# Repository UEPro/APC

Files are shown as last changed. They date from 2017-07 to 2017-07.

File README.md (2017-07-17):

# APC
Atari Punk Console<br />

This PCB was designed for a Workshop in Germany, thus the documentation is in German. Contact me if you need a translation (Contact info in folder "Documentation", file "Anleitung_APC").

<b>AKF-WORKSHOP:</b></n>

Hallo ihr Lieben, ich hoffe ihr hattet alle ein tolles Festival und seid gut Heim gekommen. :)

Vielen Dank, dass ihr beim Workshop mitgemacht habt. Es hat mir riesigen Spaß gemacht, mit euch zu Arbeiten und ich hoffe auch ihr hattet Freude am basteln.

Solltet ihr irgendwelche Fragen oder Probleme haben, schreibt mir einfach über github oder schickt mir eine E-Mail (die Adresse steht in der Anleitung oben im Ordner "Documentation").

Ich werde außerdem eine Facebookseite einrichten, damit ihr mich einfacher kontaktieren könnt. Der Link dazu kommt dann hier her.

Schreibt mir gerne auch für weiteres Feedback und Vorschläge.

Nochmals Danke für die tolle Zeit mit euch und das nette Feedback :) Ich hoffe man sieht sich wieder.

Downloadanleitung:<br />
-Einzelne Datei: Rechtsklick auf die Datei → "Ziel speichern unter" anklicken<br />
-Ganzes Archiv: oben rechts den grünen Knopf "Clone or download" anklicken → "Download as ZIP" anklicken → ZIP Archiv entpacken

This project is based on Forrest Mims' III. "Stepped Tone Generator" as published in his great book series "Engineer's Mini-Notebook".

<br /><span xmlns:dct="http://purl.org/dc/terms/" property="dct:title">Atari Punk Console</span> by <a xmlns:cc="http://creativecommons.org/ns#" href="https://github.com/UEPro/" property="cc:attributionName" rel="cc:attributionURL">Useless Electronics Projects</a> is licensed under a <a rel="license" href="http://creativecommons.org/licenses/by-sa/4.0/">Creative Commons Attribution-ShareAlike 4.0 International License</a>.<br />

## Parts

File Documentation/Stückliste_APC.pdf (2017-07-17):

## AtariPunkConsole – Bill of Materials (github.com/UEPro/APC)

Type | Manufacturer | Model | Specification | Package | Value | N | Part-Nr | Designators
Resistor | Royal Ohm | Metal film resistor | 0,6W; 250V; 50ppm/K | THT-axial | 1 kΩ ±1% | 1 MF006FF1001A50 | | R3
Resistor | Royal Ohm | Metal film resistor | 0,6W; 250V; 50ppm/K | THT-axial | 10 kΩ ±1% | 1 MF006FF1002A50 | | R2
Resistor | Royal Ohm | Metal film resistor | 125mW; 150V= | SMD-0805 | 100 kΩ ±1% | 1 0805S8F1003T5E | | R1
Potentiometer | Alps | R12L | log. stereo | THT-radial | 10 kΩ | 1 RK12L12C0A0G | | VR3
Potentiometer | Generic | | lin. mono | THT-radial | 500 kΩ | 2 | | VR1-2
Capacitor | Kemet | MLCC | 50V; X7R | THT 100mil | 10 nF ±20% | 2 C315C103M5R5TA | | C4, C7
Capacitor | Kemet | MLCC | 50V; X7R | THT 200mil | 100 nF ±10% | 2 C322C104K5R5TA | | C3, C6
Capacitor | Kemet | Polyester Capacitor | 63VAC; 100VDC | THT 200mil | 10 nF ±10% | 1 R82EC2100DQ50K | | C2
Capacitor | Kemet | Polyester Capacitor | 63VAC; 100VDC | THT 200mil | 100 nF ±10% | 1 R82EC3100DQ70K | | C5
Capacitor | Wima | Polyester Capacitor | 63VAC; 100VDC | THT 200mil | 2,2 µF ±10% | 2 | MKS2D042201N00KO 00 | C8-9
Capacitor | Nichicon | Electrolytic Capacitor | 16V; ø6,3mm | THT-radial | 220 µF ±20% | 1 UVZ1C221MED | | C1
Diode | Diotec | ZMM4.7 | Z-Diode; 0,5W | MiniMELF | 4,7 V | 1 ZMM4.7 | | D1
Diode | Optosupply | LED | cyan 3mm | THT-radial | | 1 OSC34L3131A | | D2
Transistor | Fairchild | FDN304 | P-Ch. MOSFET | SOT-23 | | 1 FDN304P | | Q1
IC | TI | NE555 | | DIP-8 | | 2 NE555P | | U1-2
Switch | Generic | | SPDT Slide Switch | THT-radial | | 1 | | S1
Connector | Generic | Pin header | 1x2pin | THT 100mil | | 1 | | J1, J2
Connector | Generic | Pin header connector | 1x2pin | THT 100mil | | 1
Connector | Generic | Crimp Contacts | Female | | | 2
Connector | Lumberg | | Stereo 3,5mm TRS-Jack | THT | | 1 1503 07 | | J3
Connector | Generic | Battery Clip | 9V-Block | | | 1
PCB | | | | | | 1
Case | Gainta | | | | | 1 G1068B
Speaker | NOS | | 8ohm | | | 1
Battery | Duracell | 9V Industrial | 6LR61 | | | 1

NB: These are the parts I have used, mostly because I had them in stock. Other parts with other values/tolerances or from other manufacturers may work just as well or even better.

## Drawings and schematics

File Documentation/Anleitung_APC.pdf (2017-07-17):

# Atari Punk Console

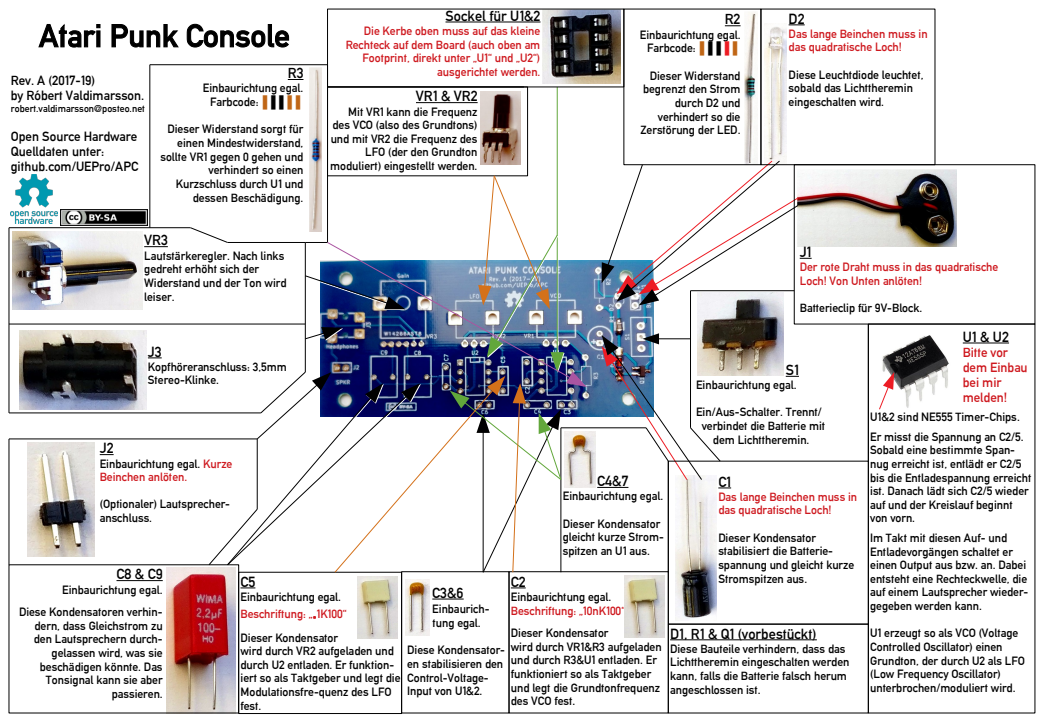
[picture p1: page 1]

Sockel für U1&2 Die Kerbe oben muss auf das kleine Rechteck auf dem Board (auch oben am Footprint, direkt unter „U1“ und „U2“) ausgerichtet werden. | R2 Einbaurichtung egal. Farbcode:▐▐▐▐▐ Dieser Widerstand begrenzt den Strom durch D2 und verhindert so die Zerstörung der LED. | D2 Das lange Beinchen muss in das quadratische Loch! Diese Leuchtdiode leuchtet, sobald das Lichttheremin eingeschalten wird.

Rev. A (2017-19)
by Róbert Valdimarsson.
robert.valdimarsson@posteo.net
Open Source Hardware
Quelldaten unter:
github.com/UEPro/APC

VR1 & VR2 Mit VR1 kann die Frequenz des VCO (also des Grundtons) und mit VR2 die Frequenz des LFO (der den Grundton moduliert) eingestellt werden.

Dieser Widerstand sorgt für
einen Mindestwiderstand,
sollte VR1 gegen 0 gehen und

Lautstärkeregler. Nach links
gedreht erhöht sich der
Widerstand und der Ton wird
leiser.

Der rote Draht muss in das quadratische
Loch! Von Unten anlöten!

Ein/Aus-Schalter. Trennt/
verbindet die Batterie mit
dem Lichttheremin.

U1&2 sind NE555 Timer-Chips.
Er misst die Spannung an C2/5.
Sobald eine bestimmte Span-
nug erreicht ist, entlädt er C2/5
bis die Entladespannung erreicht
ist. Danach lädt sich C2/5 wieder
auf und der Kreislauf beginnt
von vorn.
Im Takt mit diesen Auf- und
Entladevorgängen schaltet er
einen Output aus bzw. an. Dabei
entsteht eine Rechteckwelle, die
auf einem Lautsprecher wieder-
gegeben werden kann.

Das lange Beinchen muss in
das quadratische Loch!

Dieser Kondensator
stabilisiert die Batterie-
spannung und gleicht kurze
Stromspitzen aus.

Einbaurichtung egal.
Beschriftung: „10nK100“
wird durch VR1&R3 aufgeladen
und durch R3&U1 entladen. Er
funktioniert so als Taktgeber
und legt die Grundtonfrequenz
des VCO fest.

Diese Kondensatoren verhin-
dern, dass Gleichstrom zu
den Lautsprechern durch-
gelassen wird, was sie
beschädigen könnte. Das
Tonsignal kann sie aber

D1, R1 & Q1 (vorbestückt)
Diese Bauteile verhindern, dass das
Lichttheremin eingeschalten werden
kann, falls die Batterie falsch herum
angeschlossen ist.

wird durch VR2 aufgeladen und
durch U2 entladen. Er funktion-
iert so als Taktgeber und legt die
Modulationsfre-quenz des LFO
fest.

U1 erzeugt so als VCO (Voltage
Controlled Oscillator) einen
Grundton, der durch U2 als LFO
(Low Frequency Oscillator)
unterbrochen/moduliert wird.

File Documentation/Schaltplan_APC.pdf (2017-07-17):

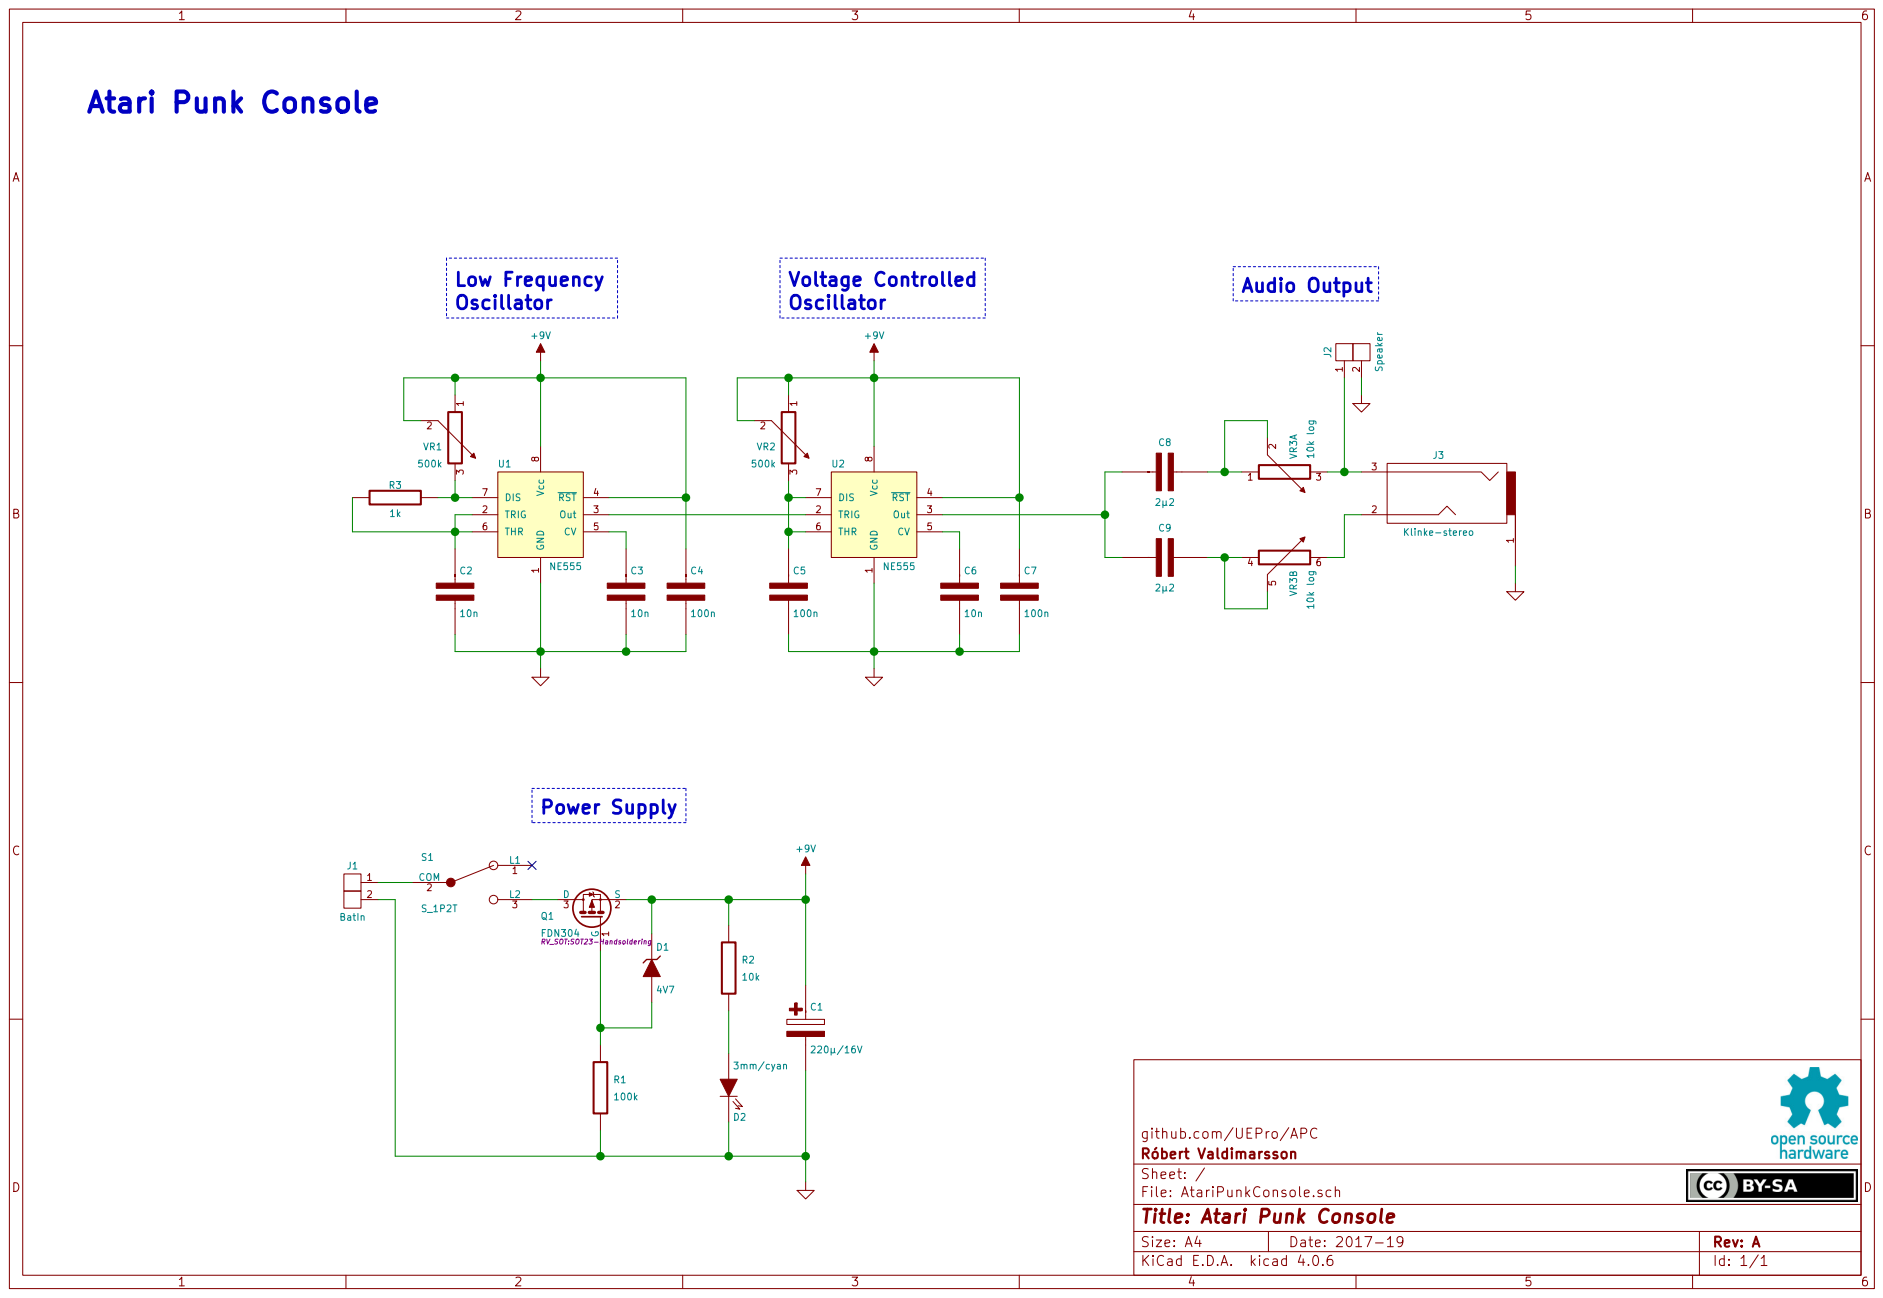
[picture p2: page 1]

1 TRIG 2 Out 3 RST 4 CV 5 THR 6 DIS 7 Vcc 8U1 NE555 GND

1 TRIG 2 Out 3 RST 4 CV 5 THR 6 DIS 7 Vcc 8U2 NE555 C3

github.com/UEPro/APC
File: AtariPunkConsole.sch Sheet: / Róbert Valdimarsson

Id: 1/1 Title: Atari Punk Console

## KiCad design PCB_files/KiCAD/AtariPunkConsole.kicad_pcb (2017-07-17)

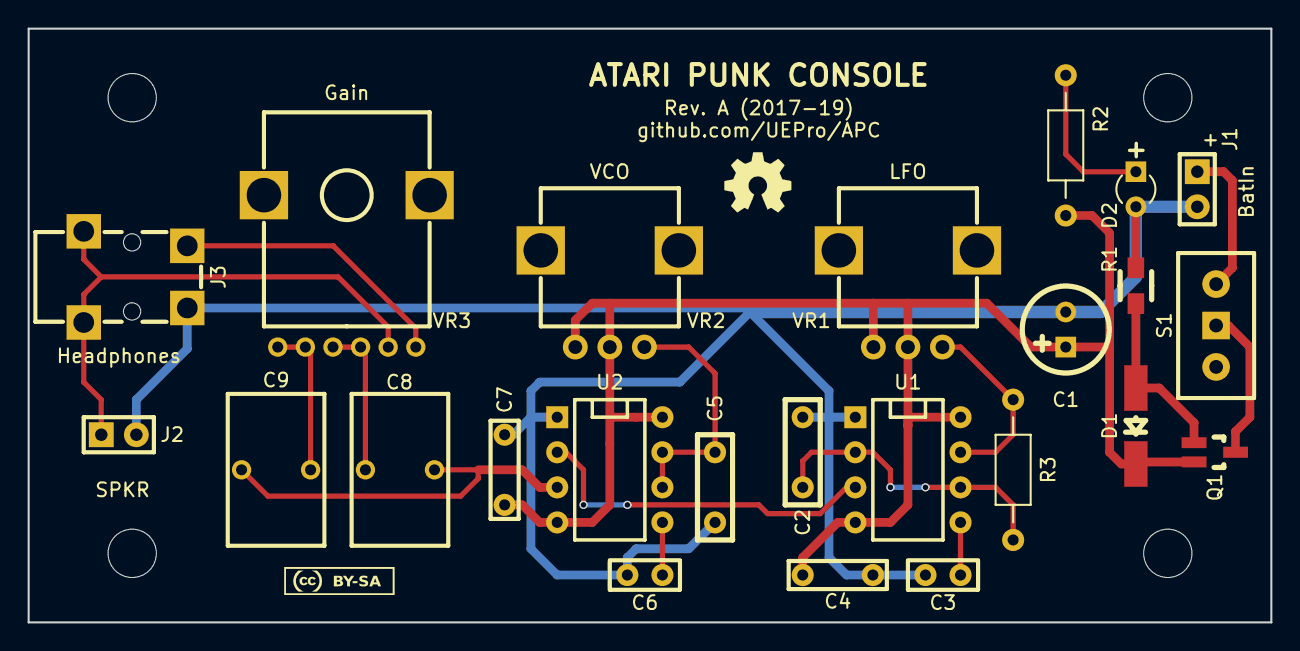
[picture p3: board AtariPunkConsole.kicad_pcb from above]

Board: 2 copper layers, 90.0 x 43.0 mm, 30 parts (0 on the bottom side), 17 nets.

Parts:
C1: 220µ/16V; C_round-radial-polar-2,5mm-6,3mm
C2: 10n; C_rect-radial-bipolar-200mil-2,5x7mm
C3, C6: 10n; C_rect-radial-bipolar-100mil-2x5mm
C4, C7: 100n; C_rect-radial-bipolar-200mil-2x7,5mm
C5: 100n; C_rect-radial-bipolar-200mil-2,5x7mm
C8, C9: 2µ2; C-Rect_L7_W11_P5
D1: 4V7; Diode_MiniMELF-Handsoldering
D2: 3mm/cyan; LED_2pin-3mm
Des*: Val*; MountingHole-3,5mm
Des*#2, Des*#3, Des*#4: Val*; MountingHole-3,5mm
J1: BatIn; PinArray-100mil-1x2
J2: Speaker; PinArray-100mil-1x2
J3: Klinke-stereo; Lumberg-1503-07-Klinke-3,5mm
Q1: FDN304; SOT23-Handsoldering
R1: 10k; SMD0805-HandSoldering
R2: 10k; R_axial_400mil
R3: 1k; R_axial_400mil
S1: S_1P2T; S-Schiebeschalter_China_SPDT
U1, U2: NE555; DIP-8_300
VAL: REF; CC-BY-SA_08mm_Fsi
VAL#2: REF; oshw5mm
VR1, VR2: 500k; VR-vert_PCB_china
VR3: 10k log; VR-Alps_R12L_vert

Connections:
+9V: C1.1, C4.1, C7.1, D1.2, Q1.2, R2.1, U1.4, U1.8, U2.4, U2.8, VR1.1, VR1.2, VR2.1, VR2.2
GND: C1.2, C2.2, C3.2, C4.2, C5.2, C6.2, C7.2, D2.2, J1.2, J2.2, J3.1, R1.2, U1.1, U2.1
unnamed: C2.1, R3.1, U1.2, U1.6
unnamed: C3.1, U1.5
unnamed: C5.1, U2.6, U2.7, VR2.3
unnamed: C6.1, U2.5
unnamed: C8.1, C9.1, U2.3
unnamed: C8.2, VR3.1, VR3.2
unnamed: C9.2, VR3.4, VR3.5
unnamed: D1.1, Q1.1, R1.1
unnamed: D2.1, R2.2
unnamed: J1.1, S1.3
unnamed: J2.1, J3.3, VR3.3
unnamed: J3.2, VR3.6
unnamed: Q1.3, S1.2
unnamed: R3.2, U1.7, VR1.3
unnamed: U1.3, U2.2
